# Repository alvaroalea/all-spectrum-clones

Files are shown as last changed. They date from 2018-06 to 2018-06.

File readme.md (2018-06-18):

# Esquema electrico en Kicad de Clones de Sinclair ZX Spectrum

La idea es que a base de borrar trozos de circuito que no interese, generemos nuestro propio clon
personalizado con las siguientes opciones:
 
* ULA - Elegir entre ALTERA o XILING
* MEMORIA RAM- 48 o 128K de RAM
* MEMORIA ROM- 16K o 64K ROM, opciones de ROM mayores con seleccion por dip-switches
* SONIDO - PSG (AY-3-8912 o YM2114), MONO O ABC, OPCION puertos SERIE, AUX
* CINTA - conectores 48K o +3, circuiteria tipo Arlequin o tipo Humble
* VIDEO - RGB o Composite, circuiteria tipo Arlequin
* JOYSTICK - SJS o ATARI, normas SINCLAIR o KEMPSTON
* TECLADO - integrado de 40 Teclas, por transistores (arlequin) o diodos
* TECLADO - conexion facil para teclas externas, DEL, BREAK, CURSORES, BLOQ SHIFT, EXTRA, GRAF
* DISCO - Conexion para interfaz multisistema de wilco (compatible +3), interfaz +D o Interfaz +3
* ALMACENAMIENTO - Interfaz IDE de 8bits, Cartucho IF2, dandanator integrado o con cartuchos VC2.0 

## Futuro:
* DISCO - beta 128, ZXMMC, DIVIDE
* MEMORIA - Usar los 256K tipo ruso
* VIDEO - conector euroconector
* ULA - por chips del arlequin
* IMPRESORA - amstrad / kempston
* RATON - kempston db9, kempston ps2

## Ejemplos:
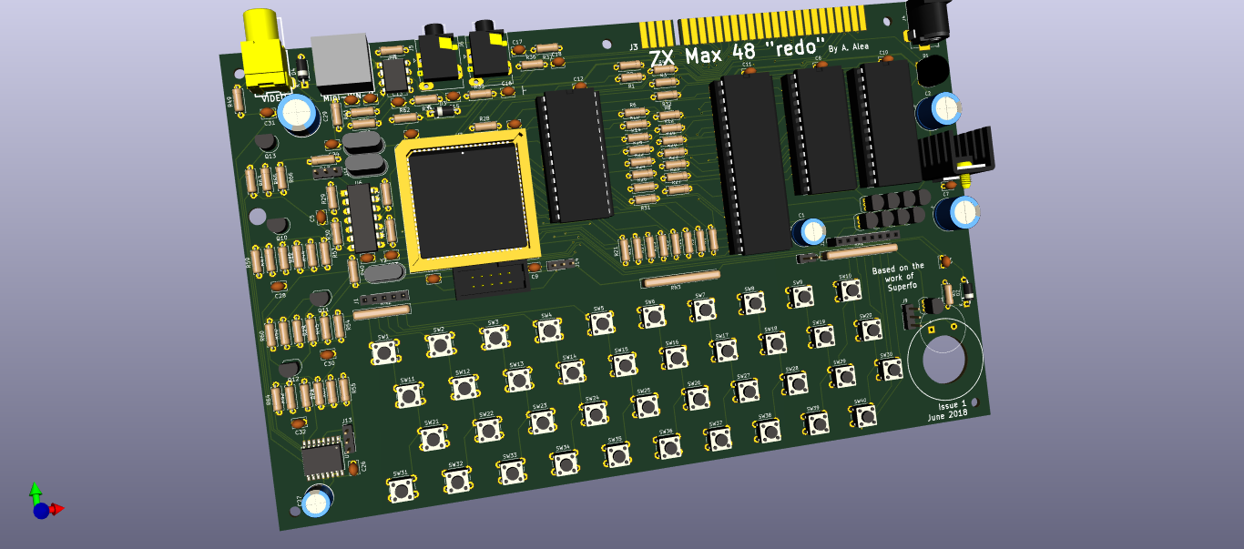
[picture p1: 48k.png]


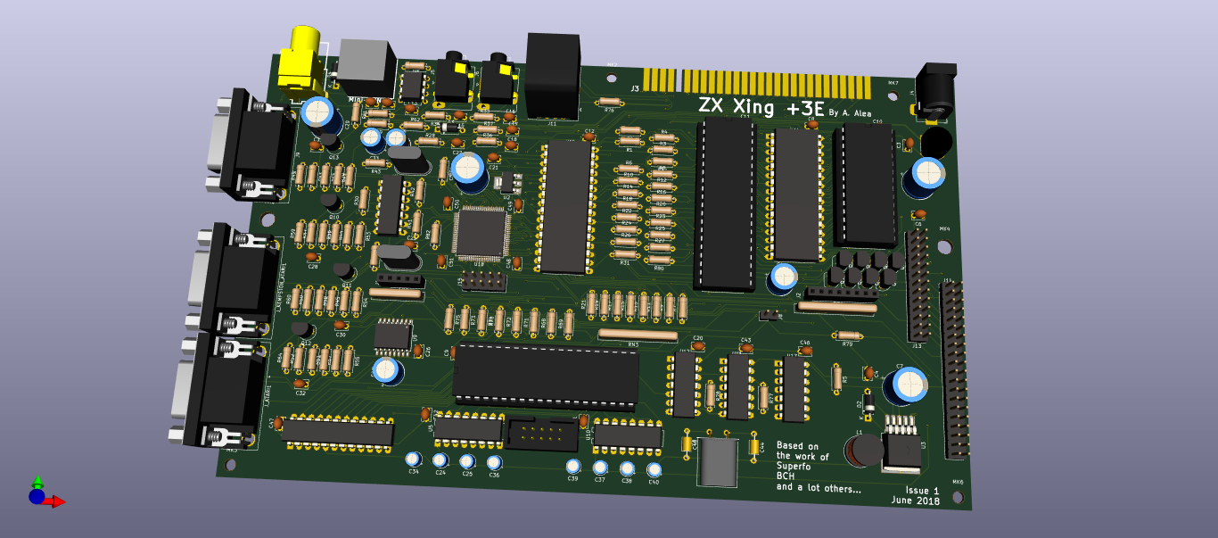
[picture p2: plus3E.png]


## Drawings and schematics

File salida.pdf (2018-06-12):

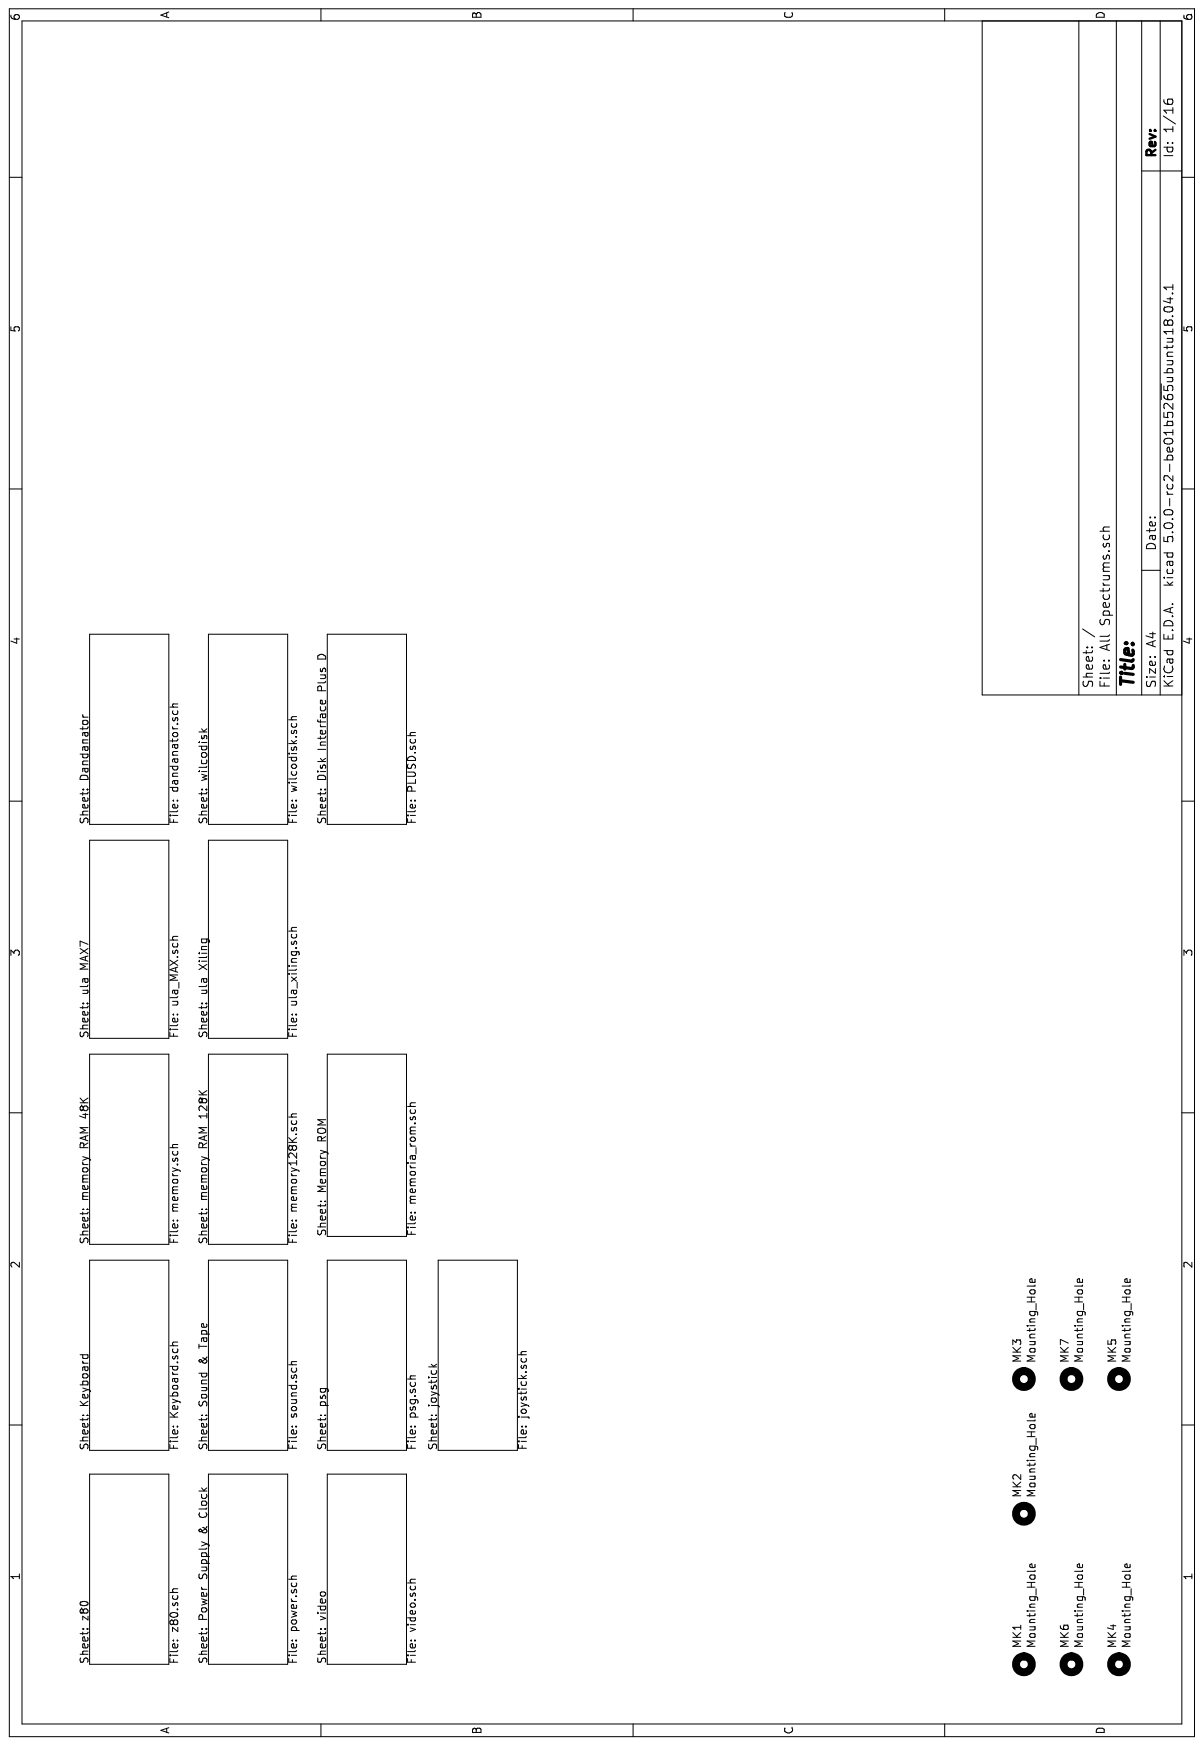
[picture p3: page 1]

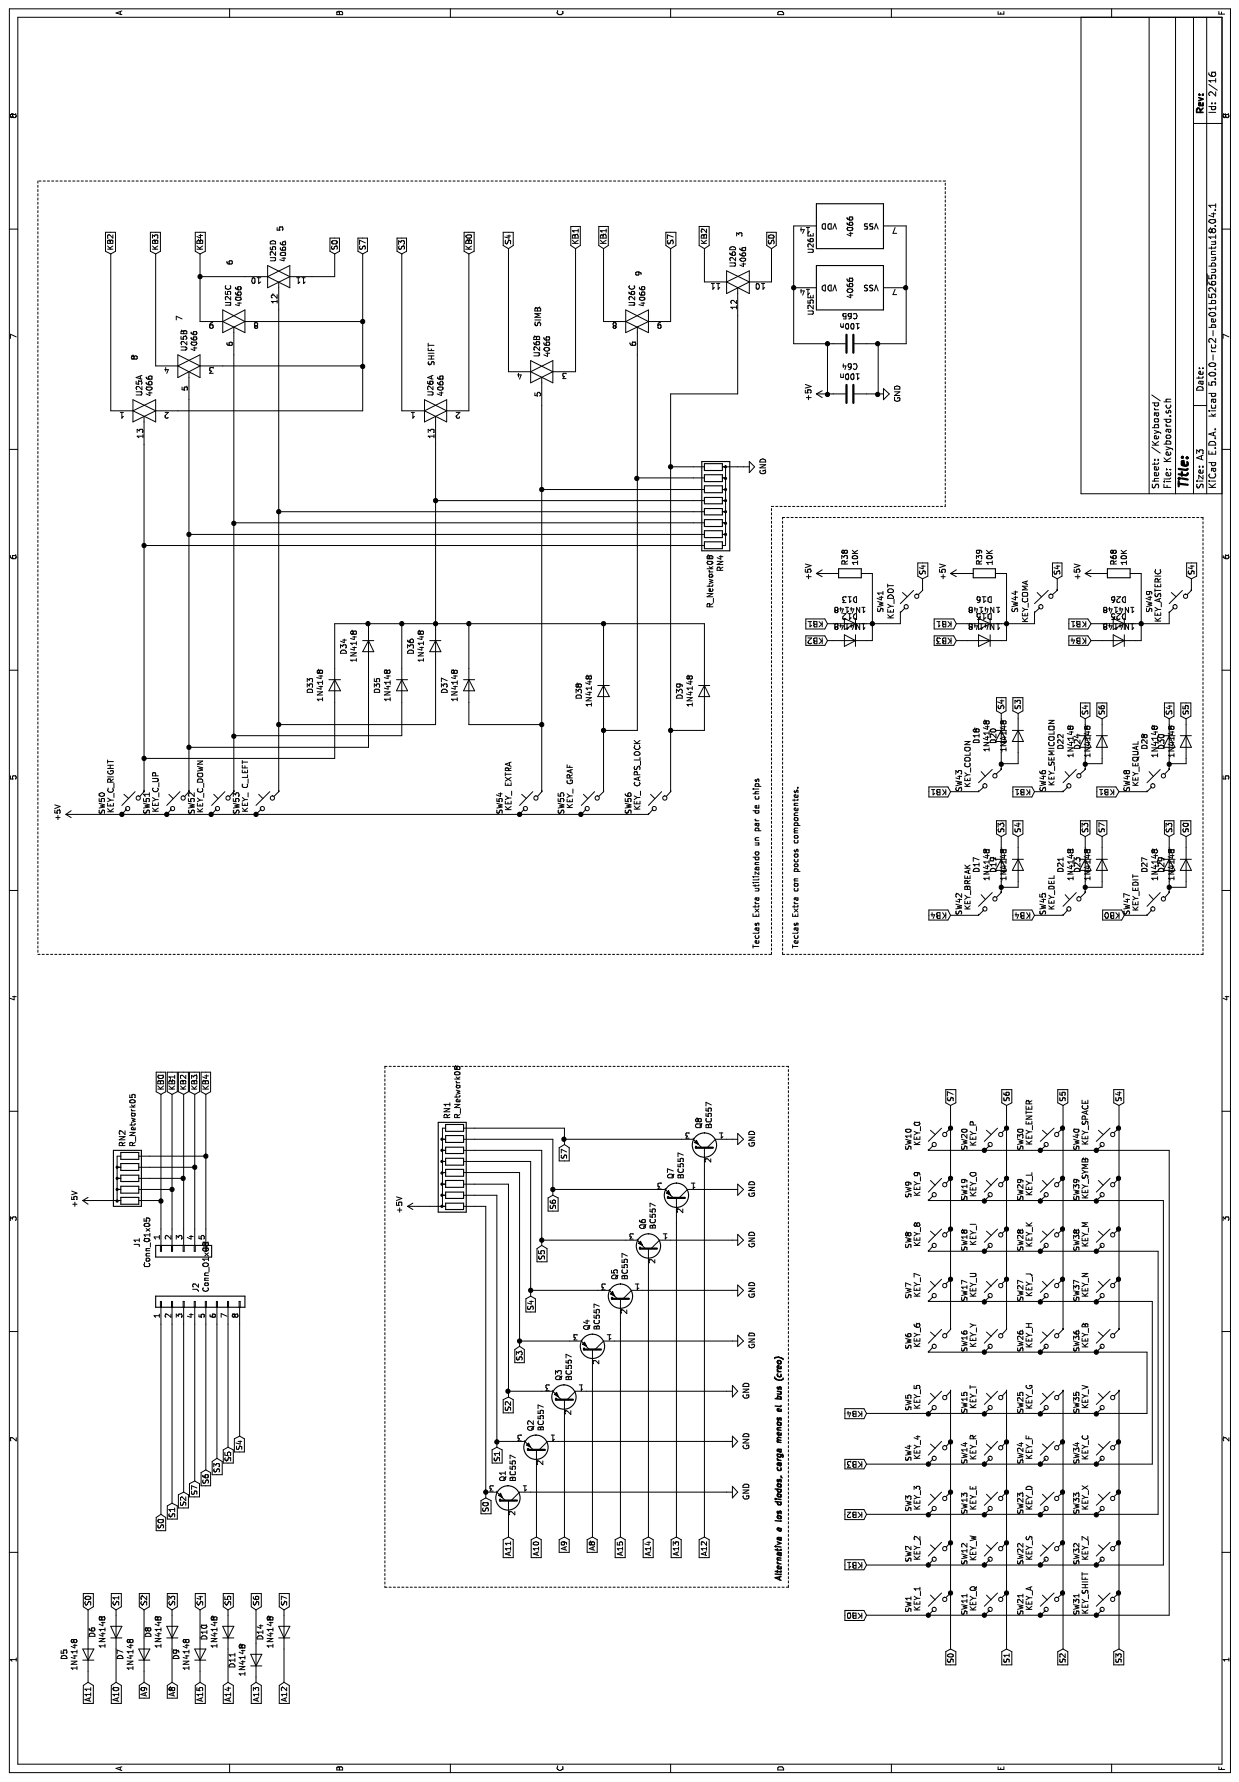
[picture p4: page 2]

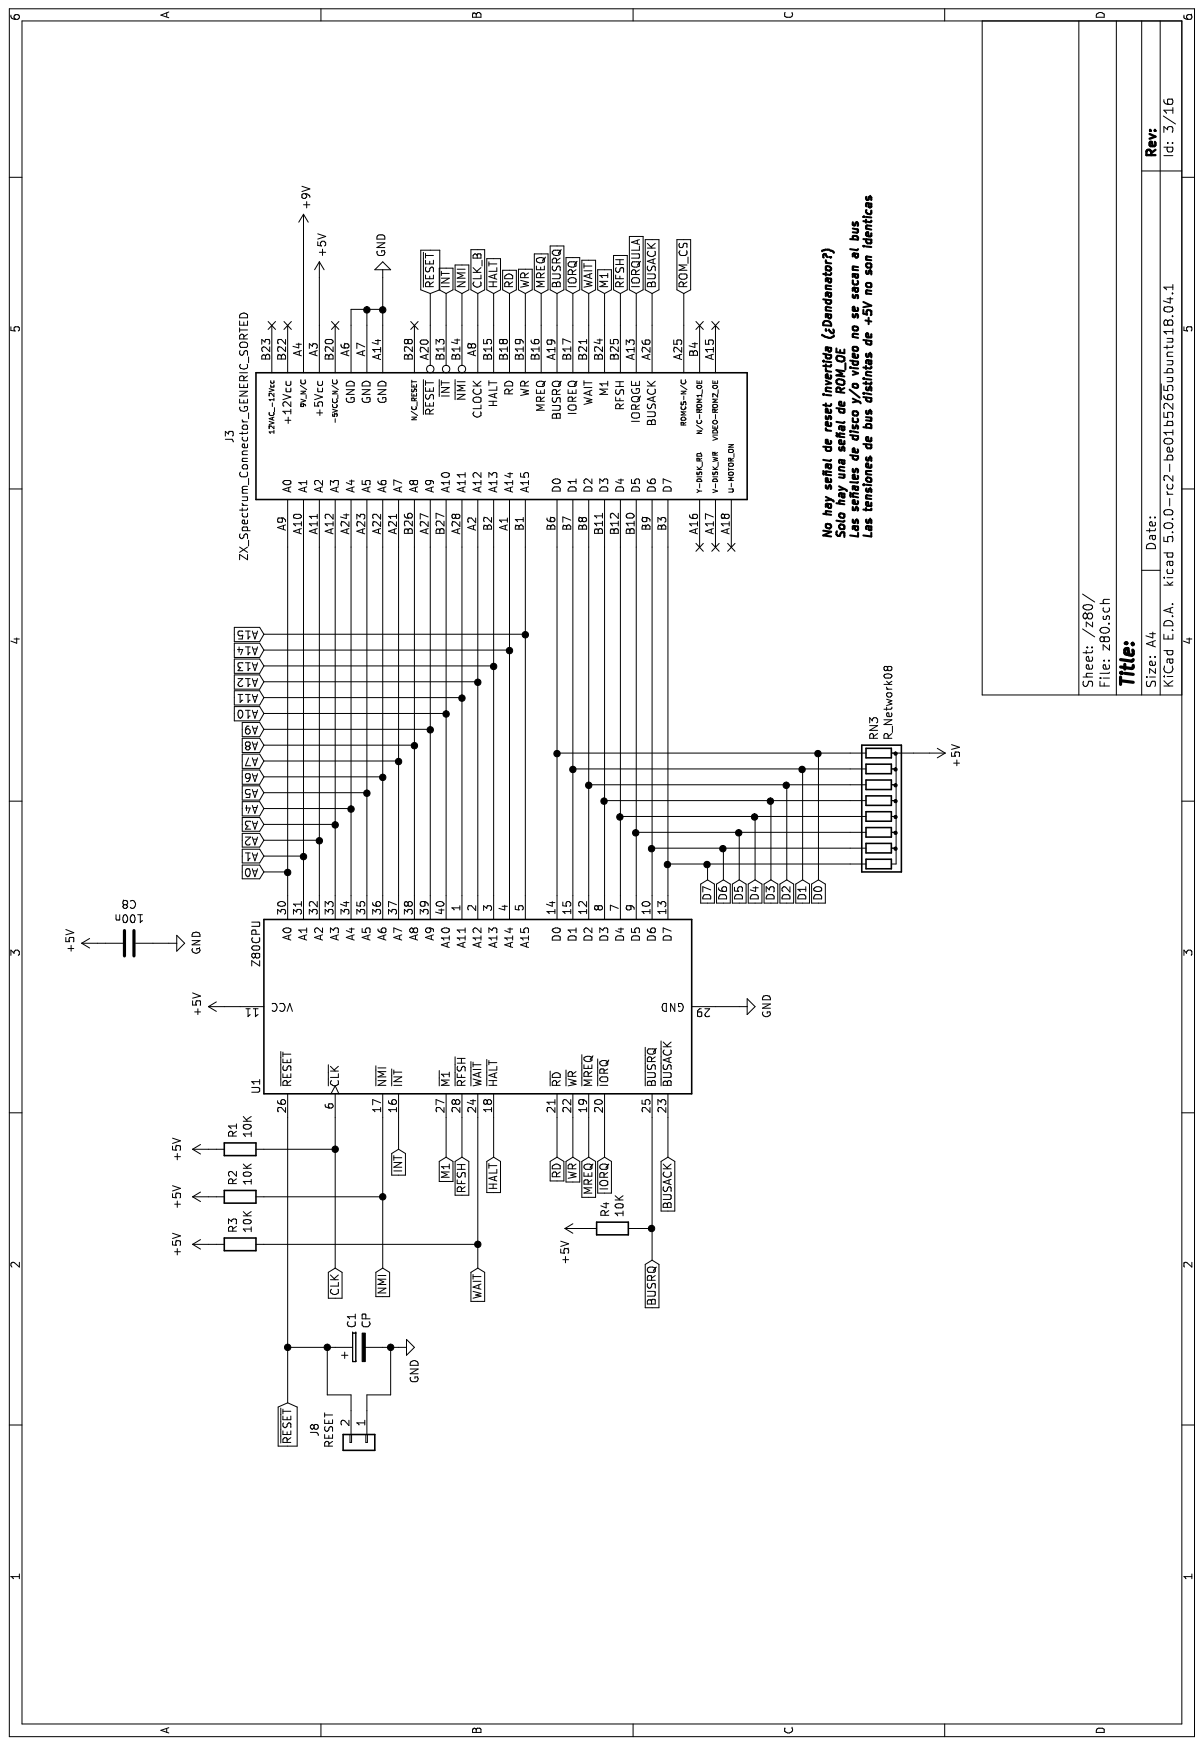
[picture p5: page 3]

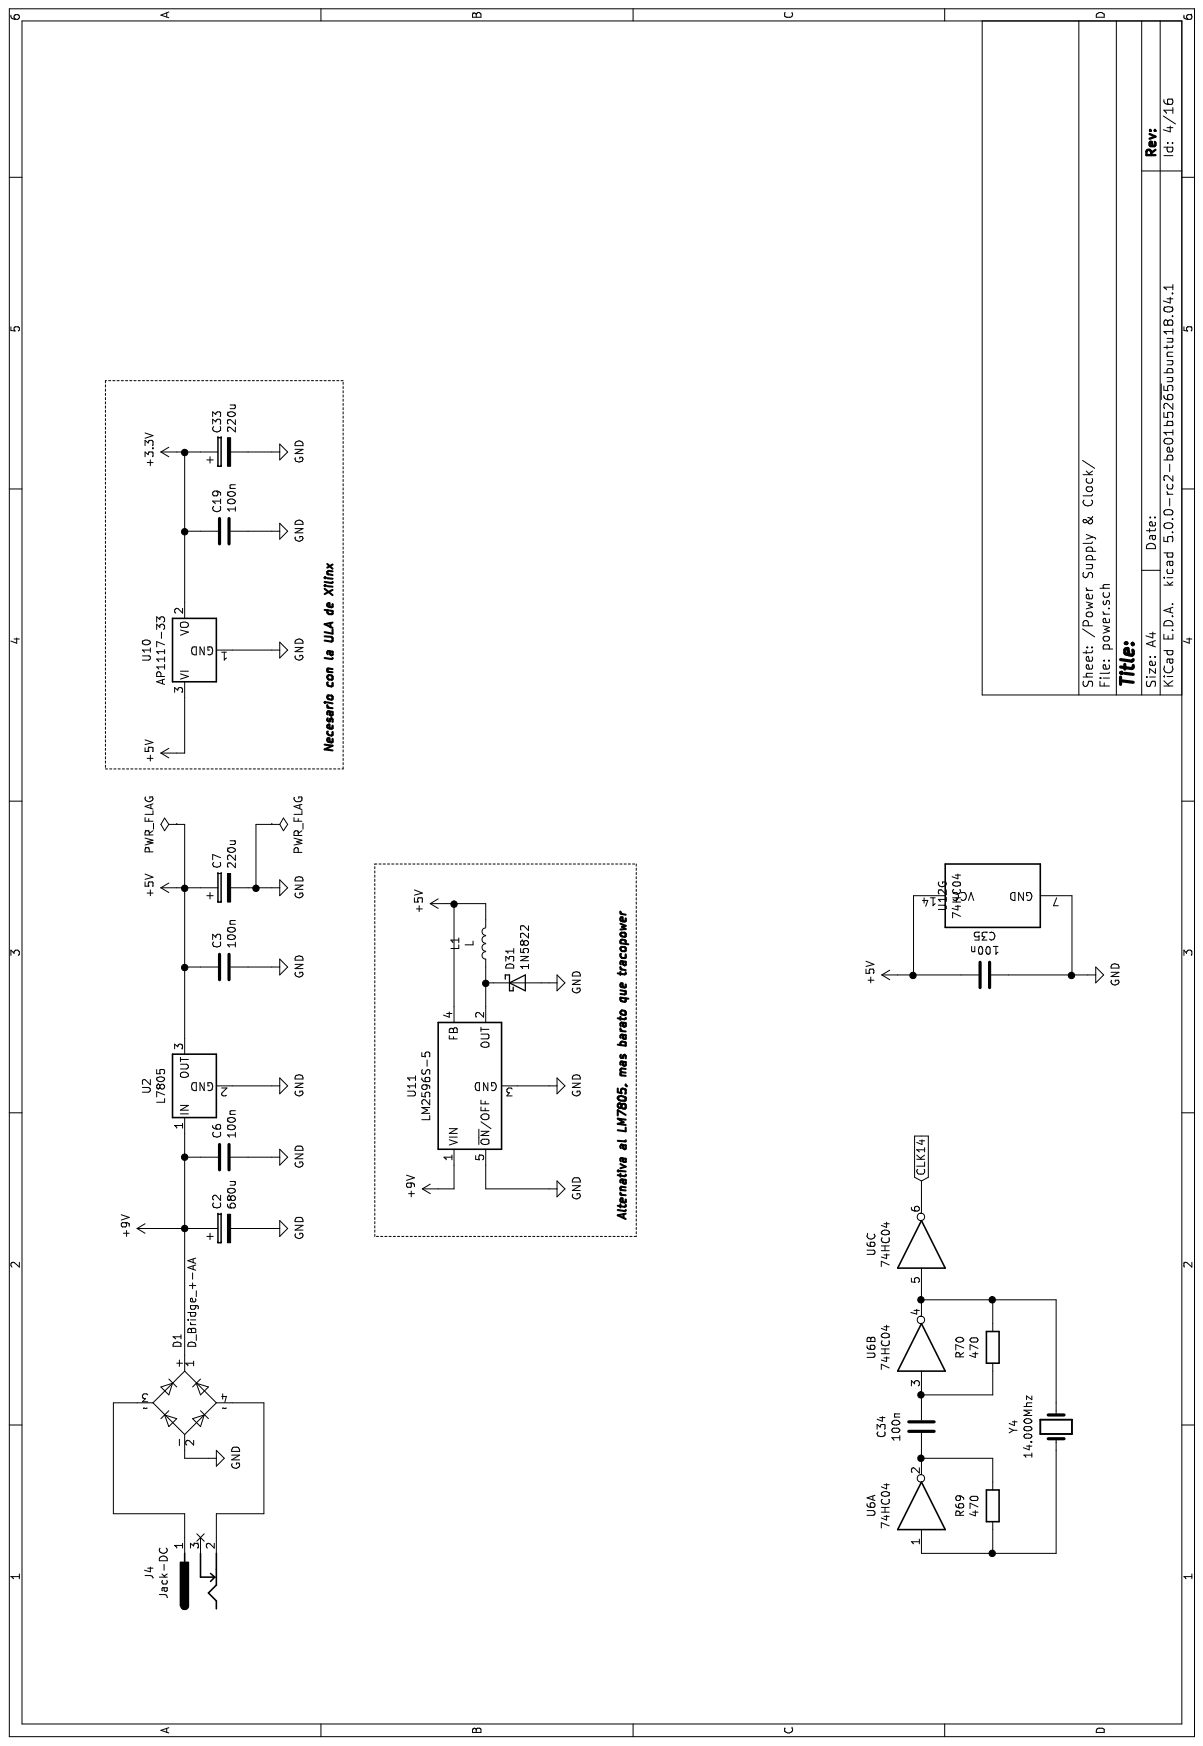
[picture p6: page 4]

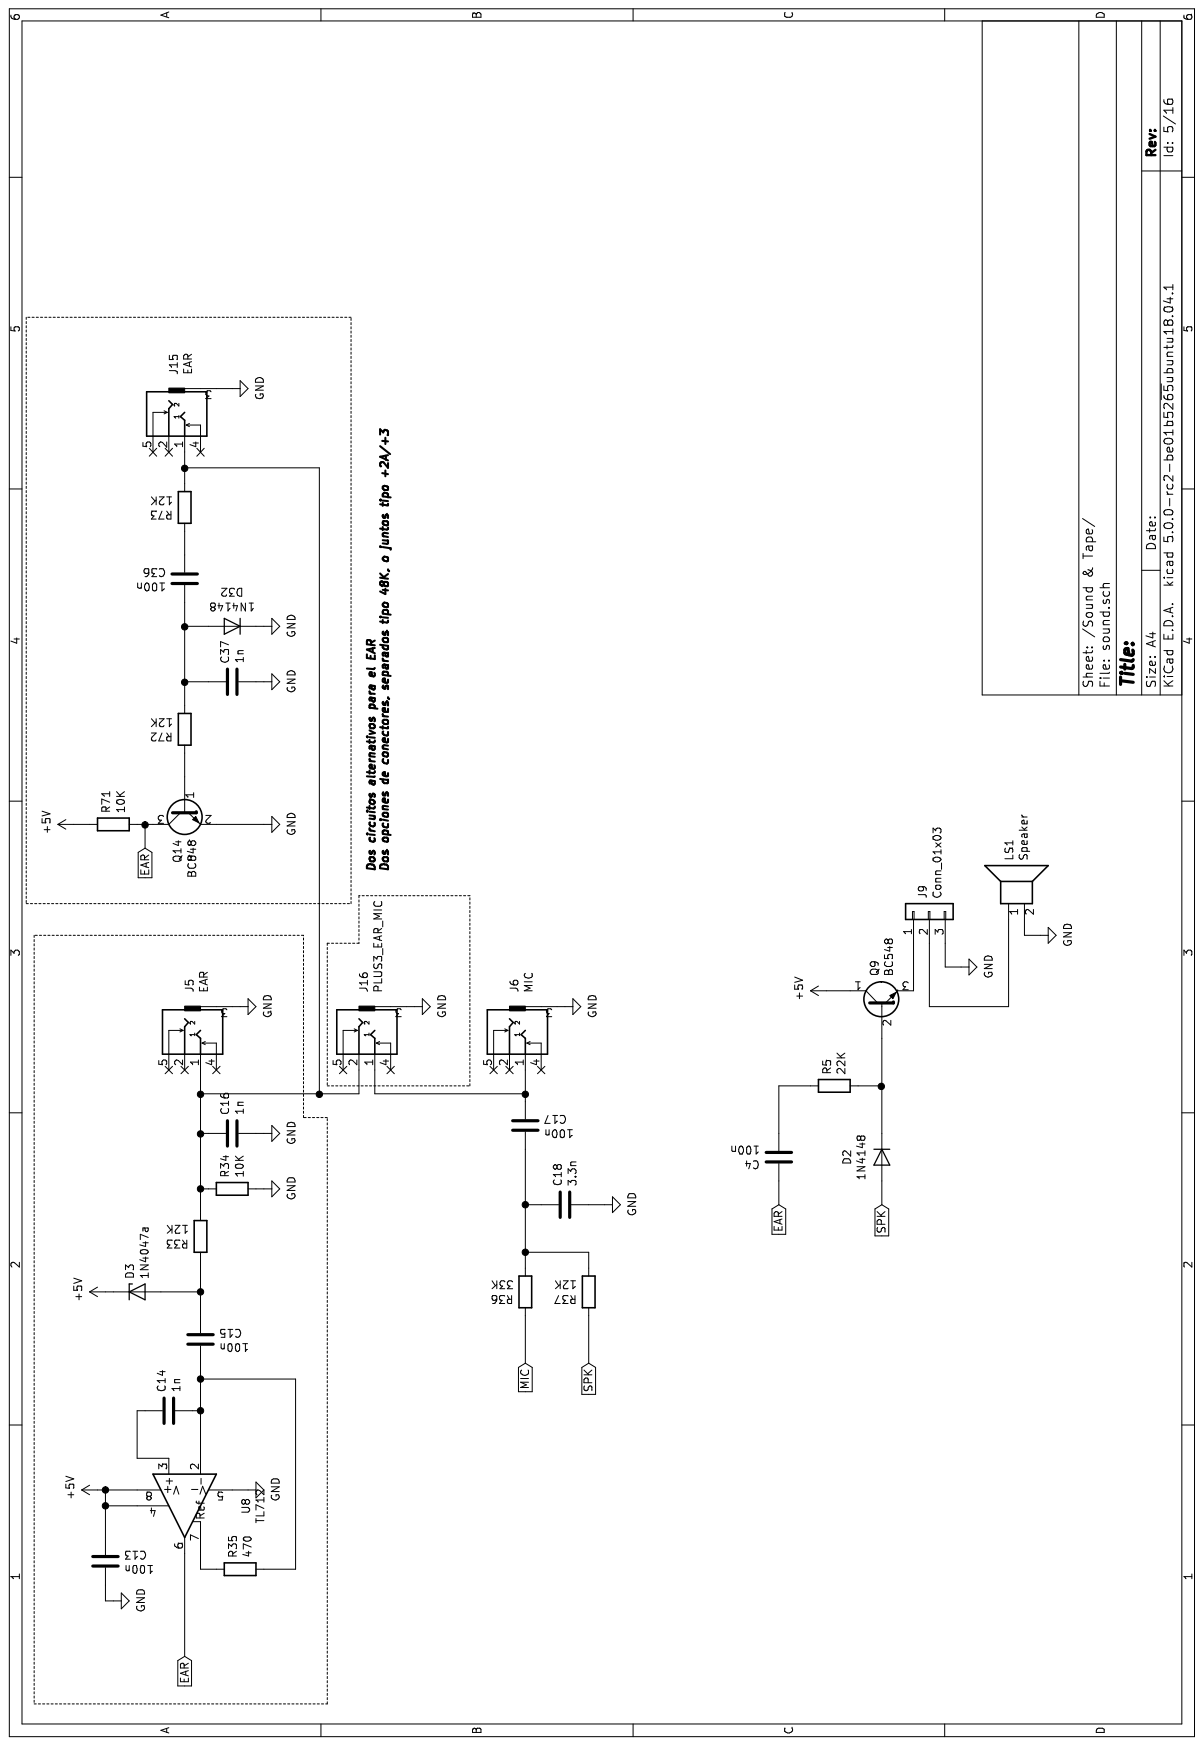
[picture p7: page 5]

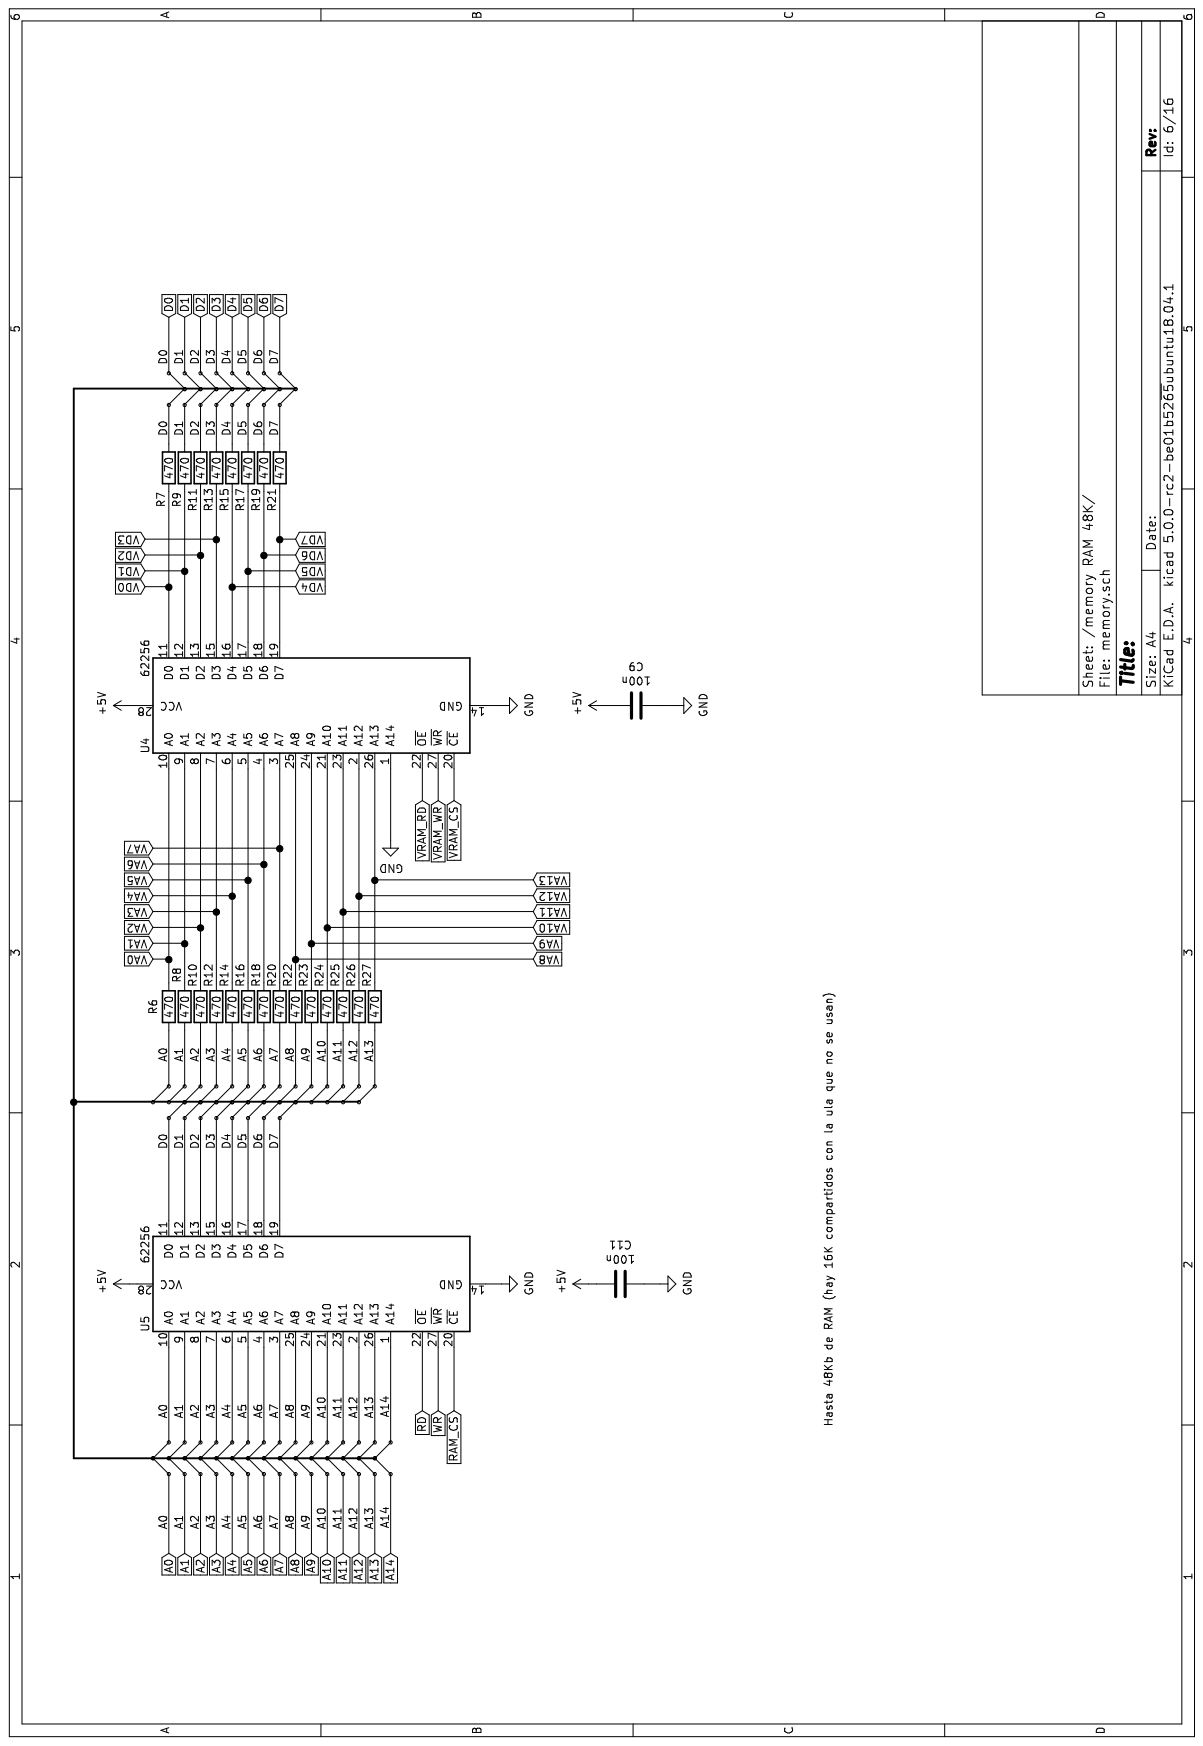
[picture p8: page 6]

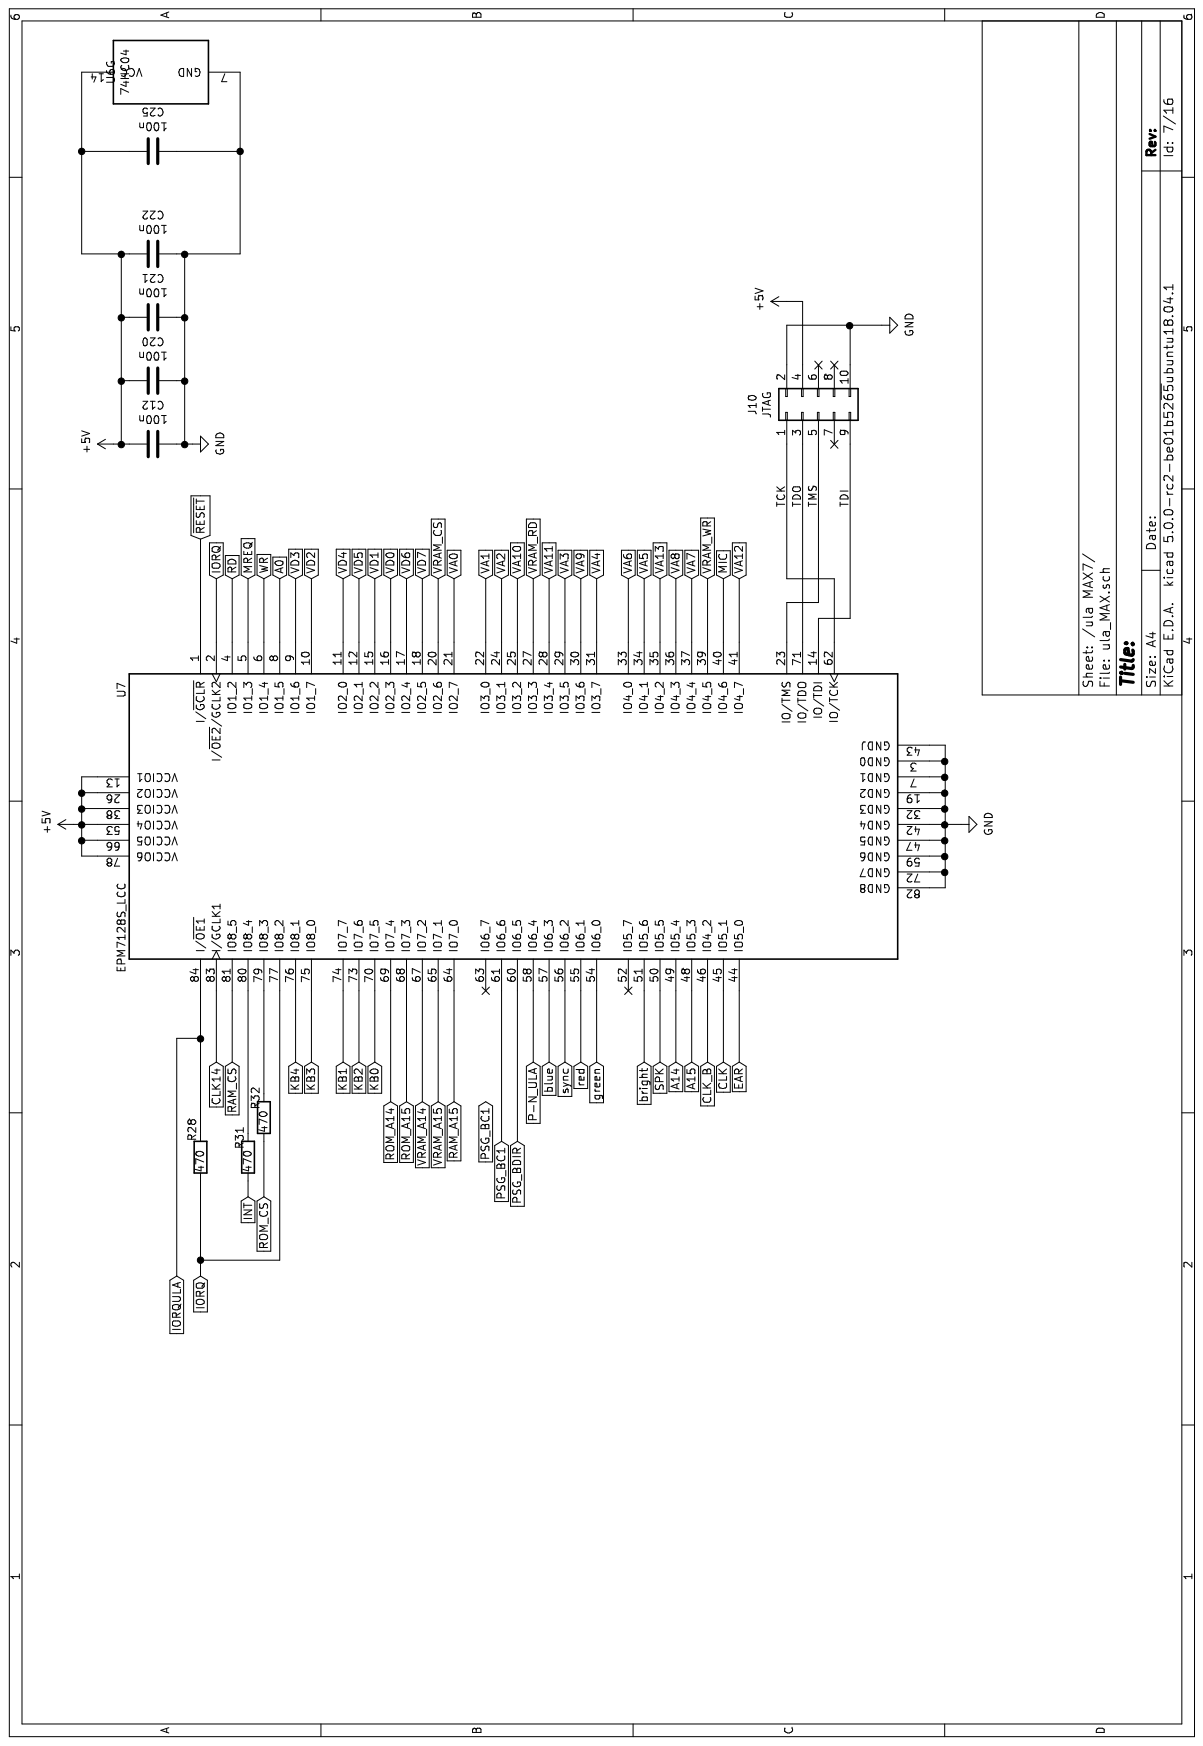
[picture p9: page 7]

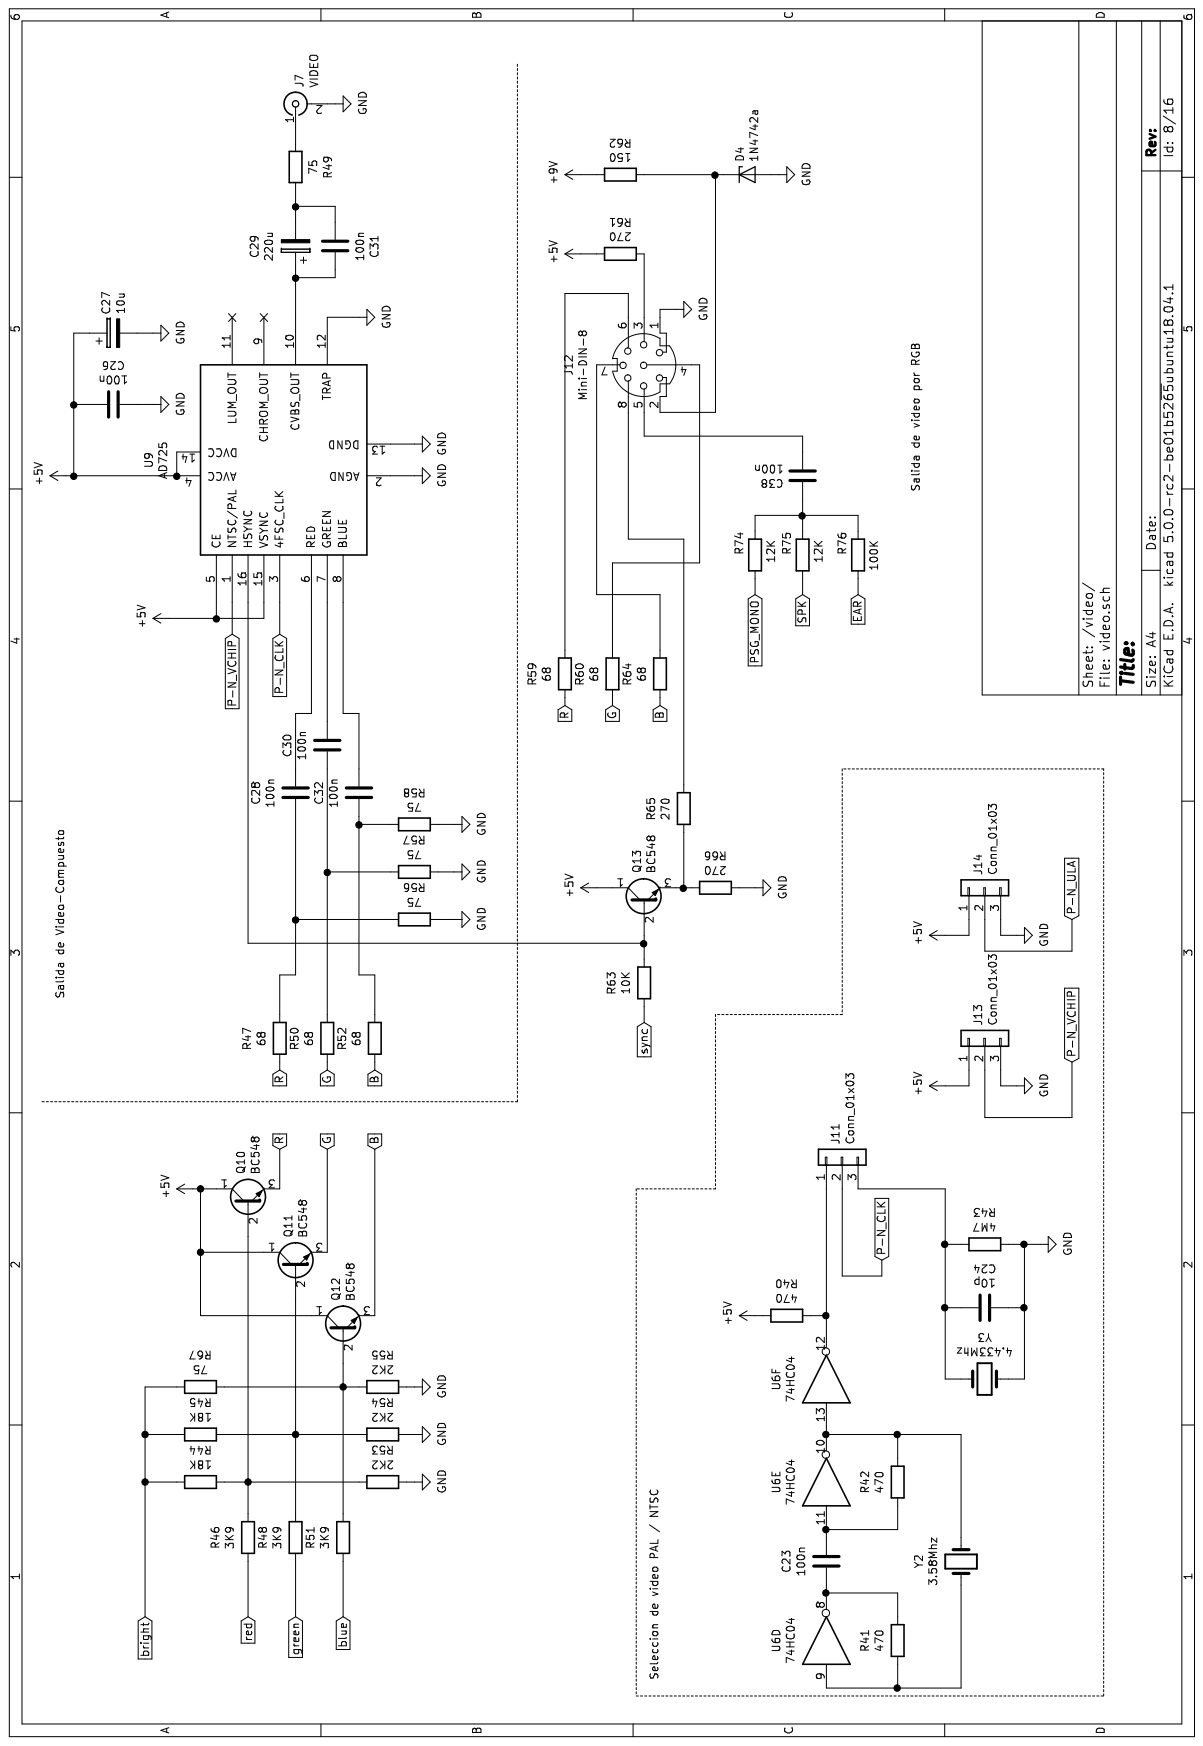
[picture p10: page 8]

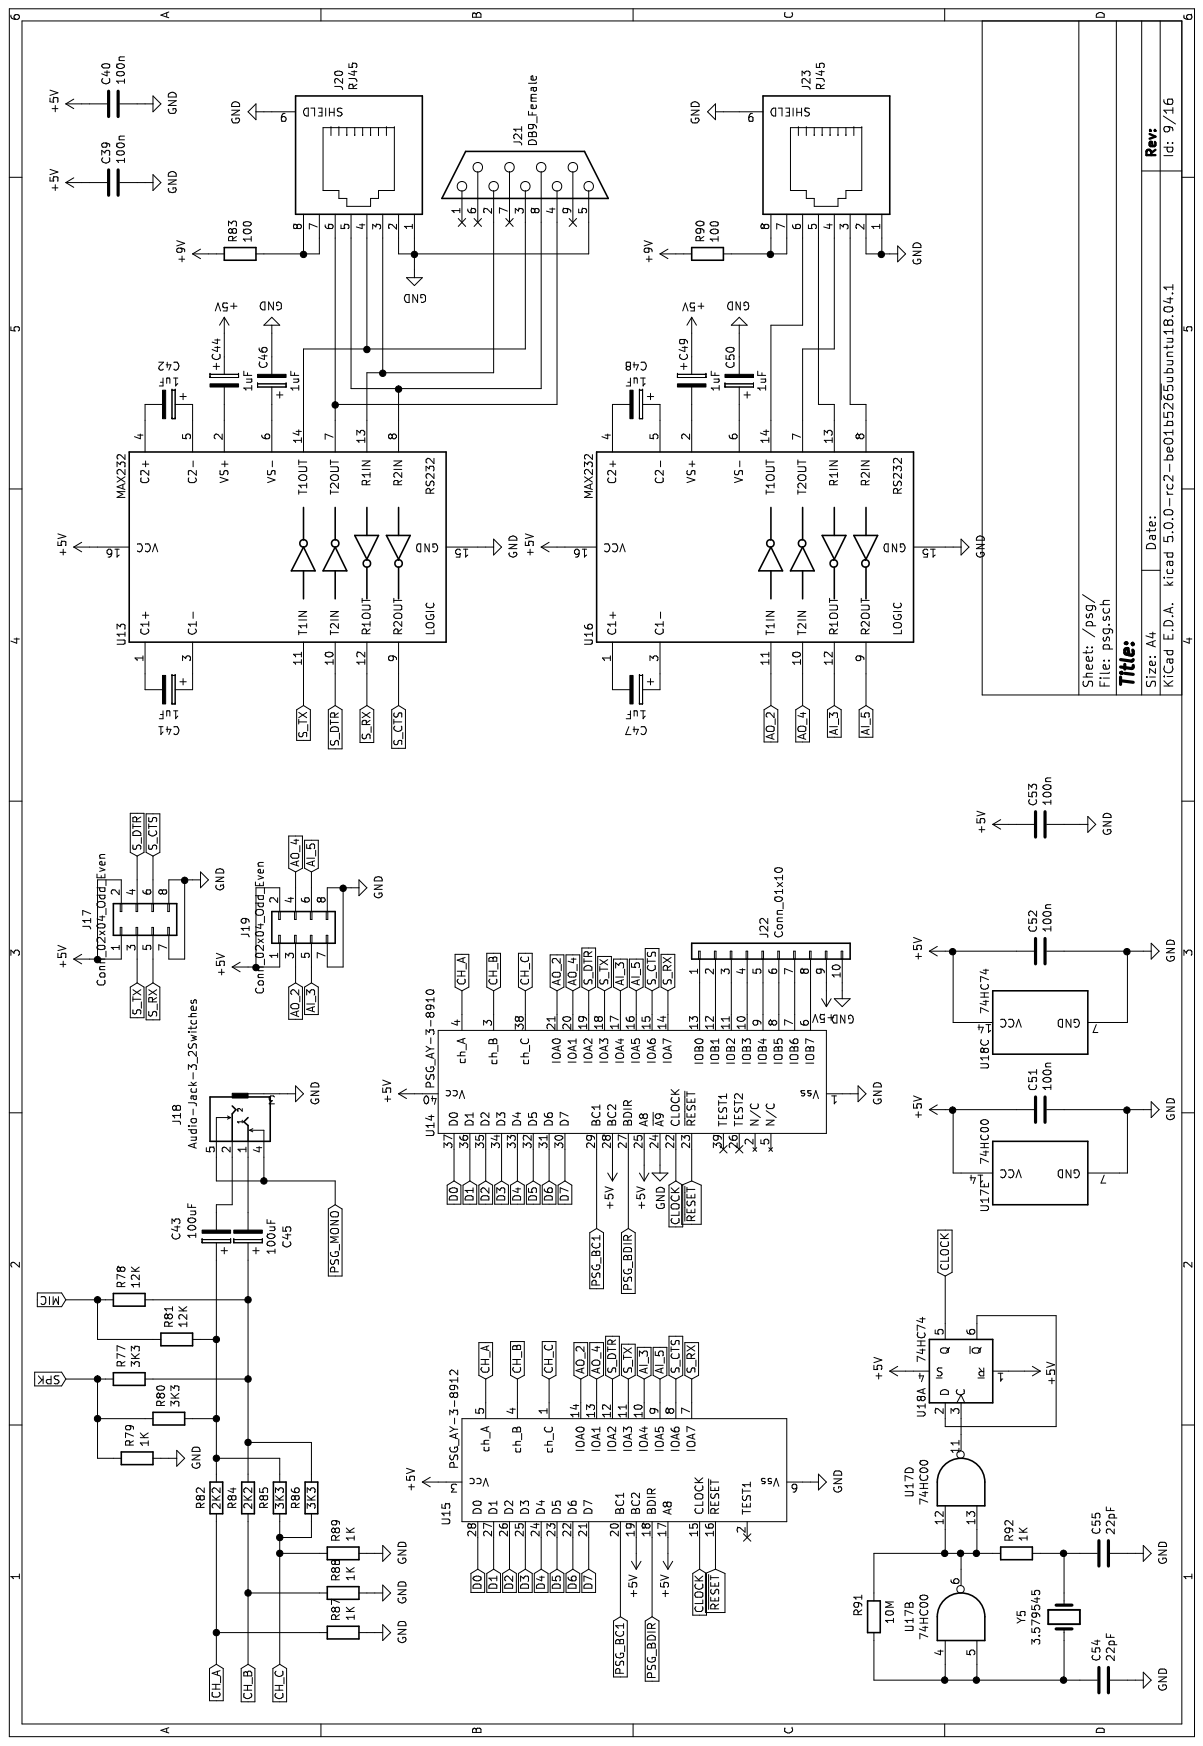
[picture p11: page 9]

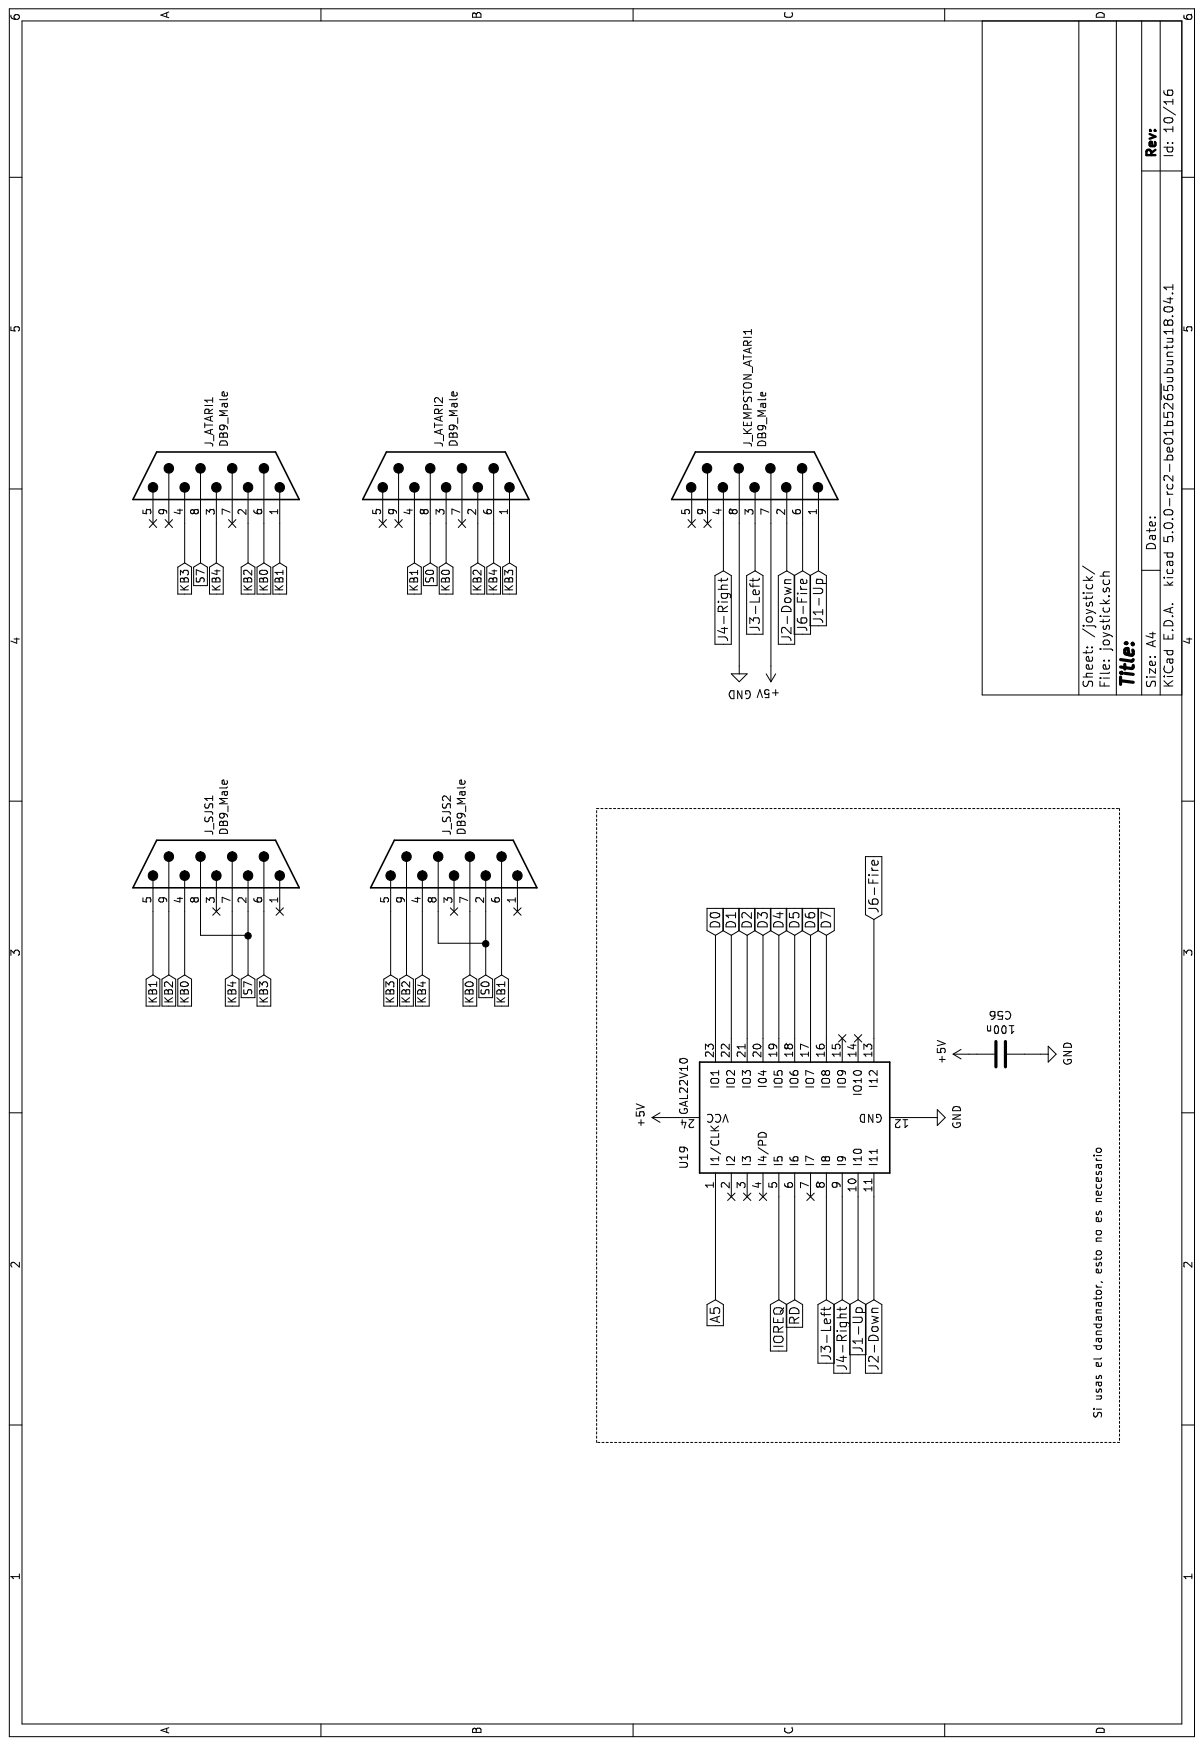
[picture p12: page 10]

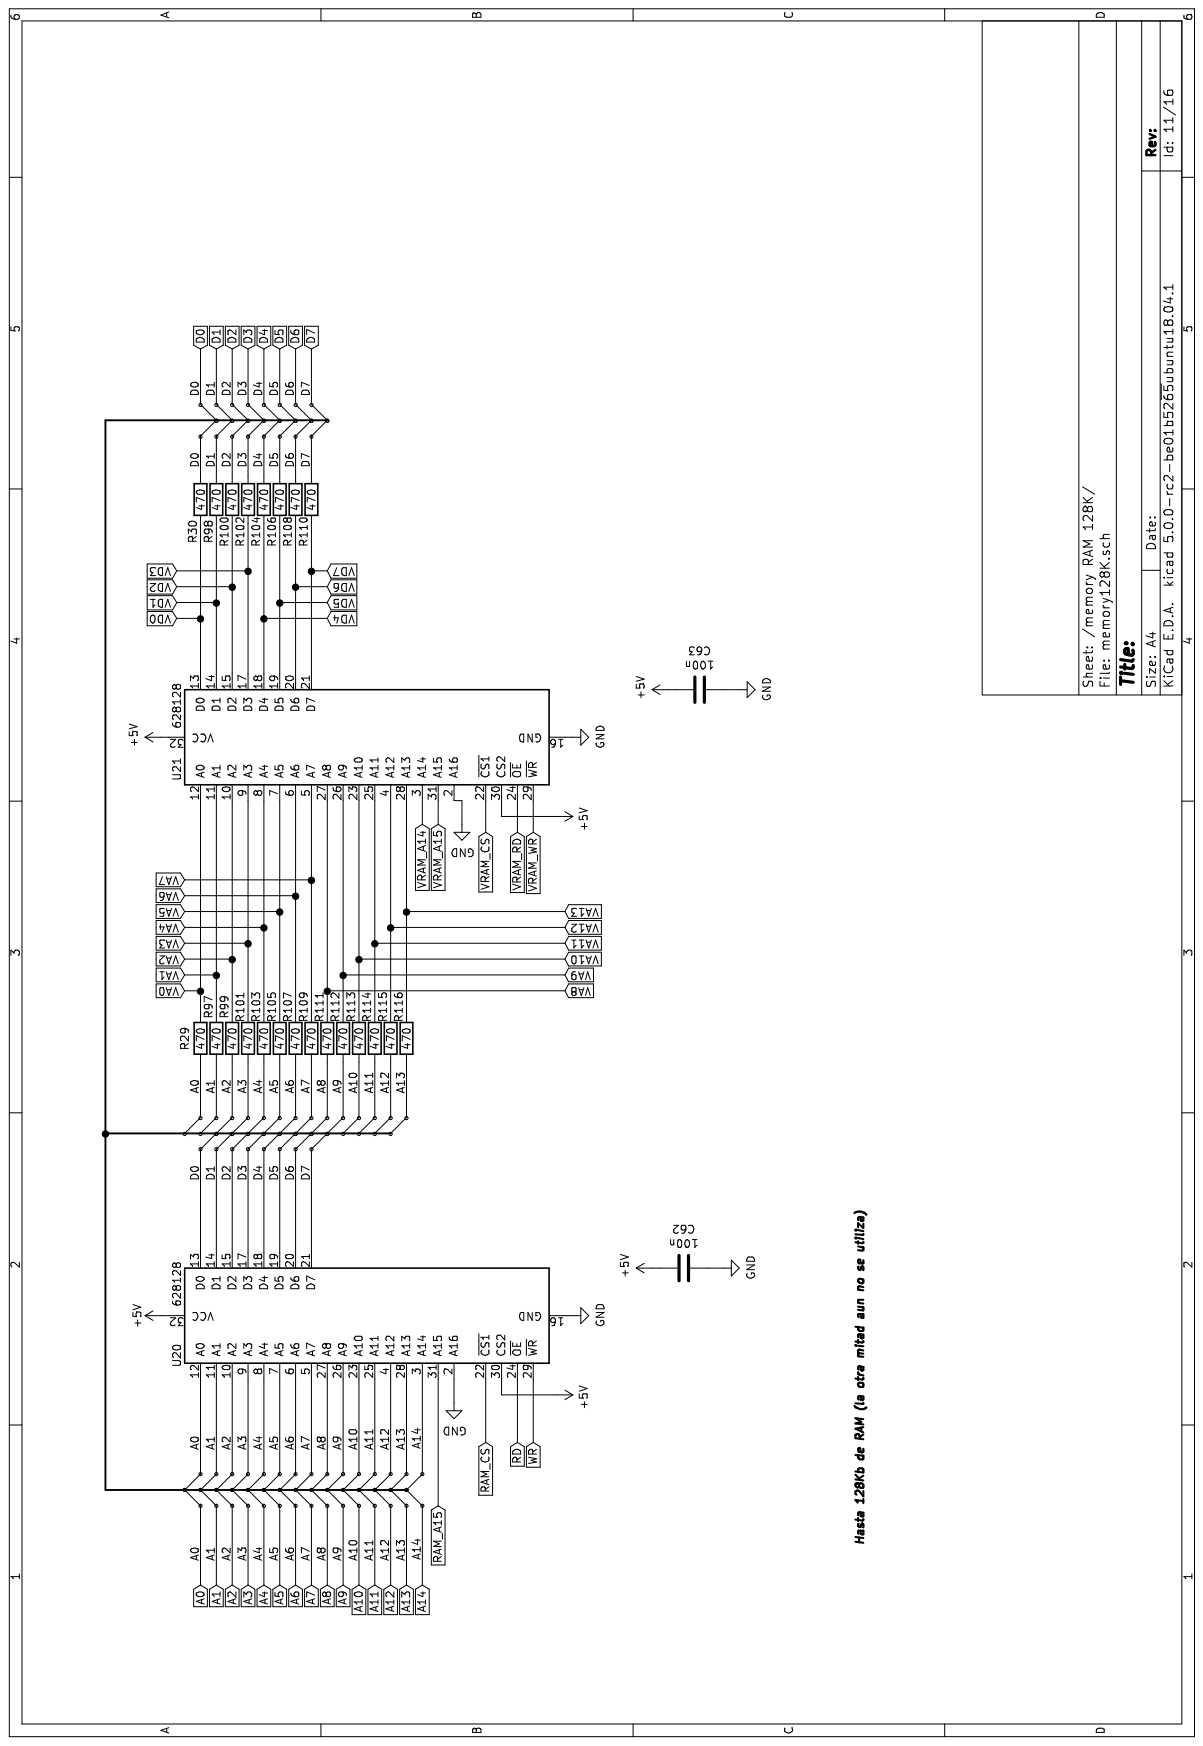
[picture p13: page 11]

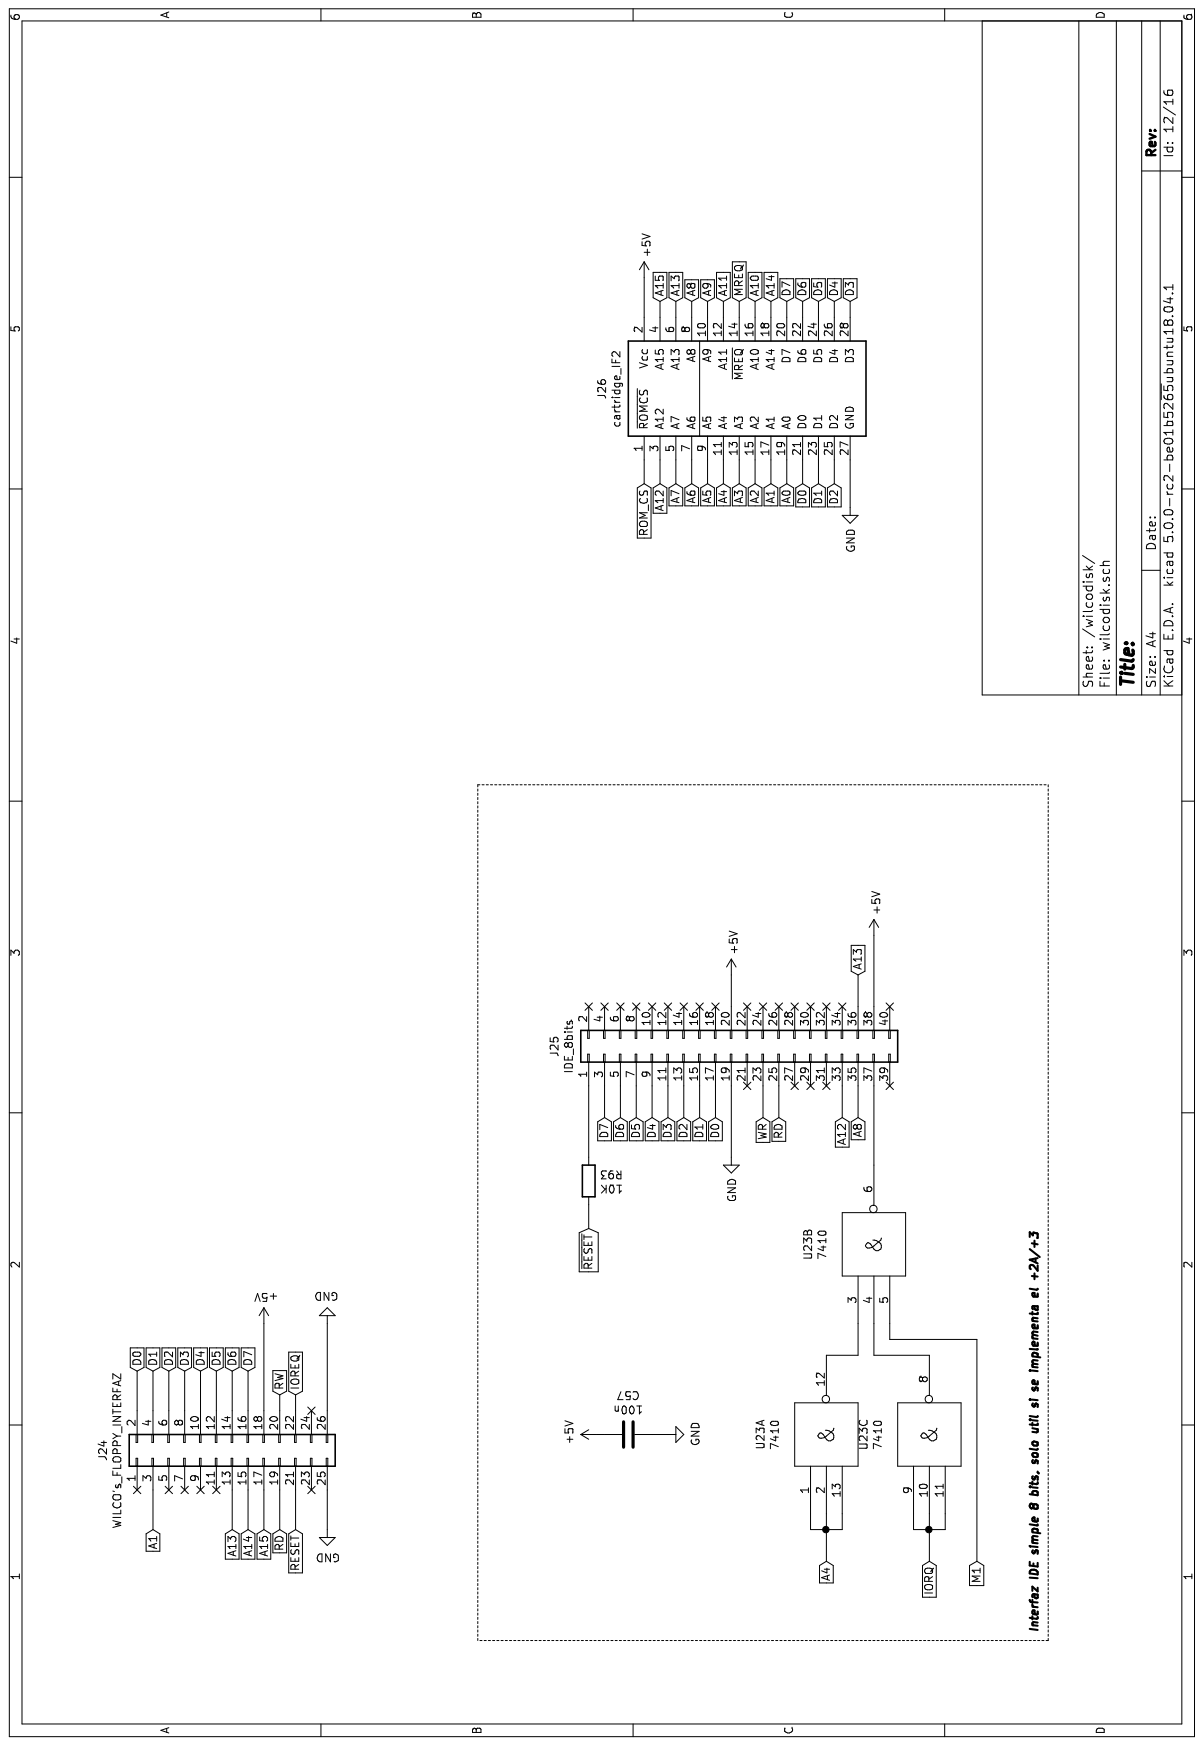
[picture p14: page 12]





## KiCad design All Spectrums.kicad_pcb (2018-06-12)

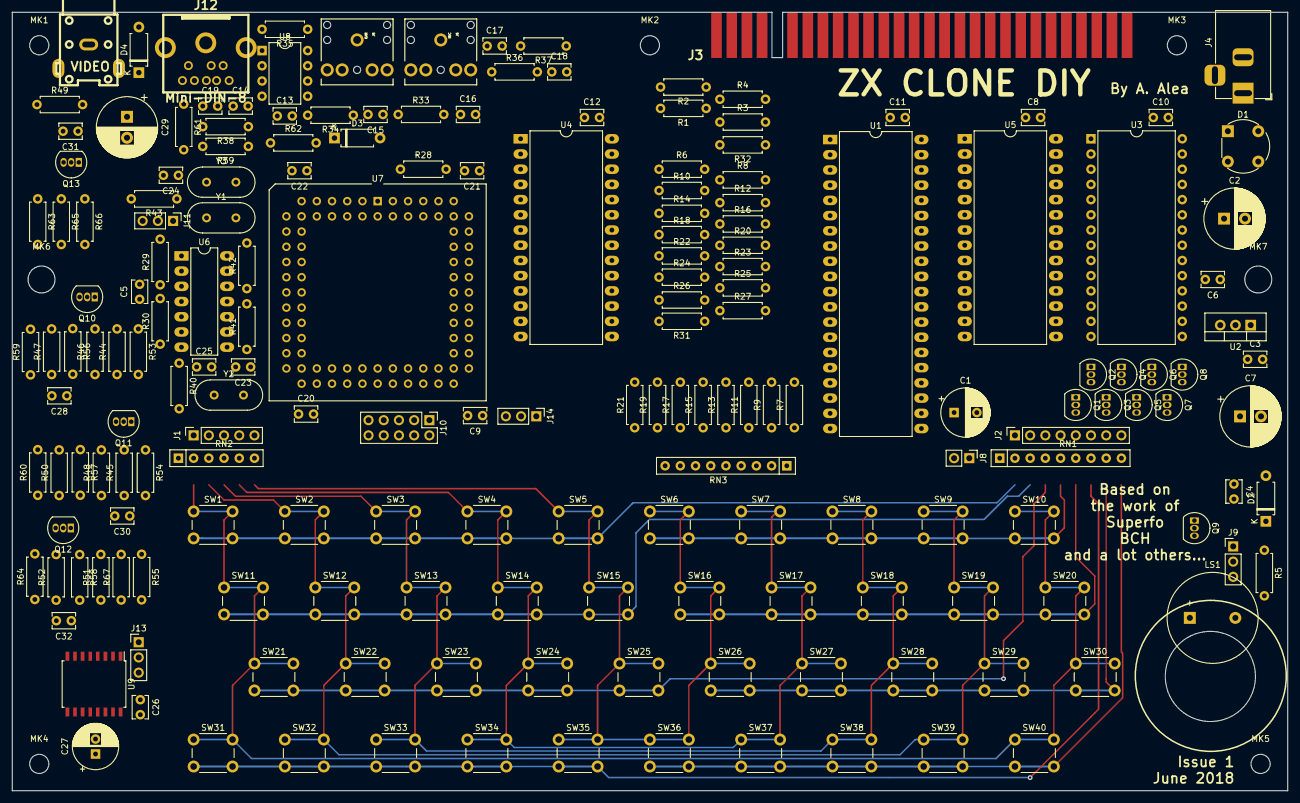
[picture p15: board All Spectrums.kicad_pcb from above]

Board: 2 copper layers, 213.0 x 130.0 mm, 193 parts (0 on the bottom side), 148 nets.

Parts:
C1: CP; CP_Radial_D8.0mm_P3.80mm
C2: 680u; CP_Radial_D10.0mm_P3.50mm
C3, C4, C5, C6, C8, C9, C10, C11, C12, C13, C15, C17, C19, C20, C21, C22, C23, C25, C26, C28, C30, C31, C32: 100n; C_Disc_D3.8mm_W2.6mm_P2.50mm
C7, C29: 220u; CP_Radial_D10.0mm_P3.50mm
C14, C16: 1n; C_Disc_D3.8mm_W2.6mm_P2.50mm
C18: 3.3n; C_Disc_D3.8mm_W2.6mm_P2.50mm
C24: 10p; C_Disc_D3.8mm_W2.6mm_P2.50mm
C27: 10u; CP_Radial_D7.5mm_P2.50mm
D1: D_Bridge_+-AA; Diode_Bridge_Round_D8.9mm
D2: 1N4148; D_A-405_P7.62mm_Horizontal
D3: 1N4047a; D_A-405_P7.62mm_Horizontal
D4: 1N4742a; D_A-405_P7.62mm_Horizontal
J1: Conn_01x05; PinSocket_1x05_P2.54mm_Vertical
J2: Conn_01x08; PinSocket_1x08_P2.54mm_Vertical
J3: ZX_Spectrum_Connector_plus3_SORTED; ZX_EDGE
J4: Jack-DC; BarrelJack_Horizontal
J5: EAR; AUDIO-JACK
J6: MIC; AUDIO-JACK
J7: VIDEO; rca_yellow
J8: RESET; PinHeader_1x02_P2.54mm_Vertical
J9, J11, J13, J14: Conn_01x03; PinHeader_1x03_P2.54mm_Vertical
J10: JTAG; PinHeader_2x05_P2.54mm_Vertical
J12: Mini-DIN-8; minidin-8
LS1: Speaker; Buzzer_15x7.5RM7.6
MK1, MK2, MK3, MK4, MK5: MountingHole_3.2mm_M3
MK6, MK7: MountingHole_4.5mm
Q1, Q2, Q3, Q4, Q5, Q6, Q7, Q8: BC557; TO-92_Inline
Q9, Q10, Q11, Q12, Q13: BC548; TO-92_Inline
R1, R2, R3, R4, R34, R63: 10K; R_Axial_DIN0207_L6.3mm_D2.5mm_P7.62mm_Horizontal
R5: 22K; R_Axial_DIN0207_L6.3mm_D2.5mm_P7.62mm_Horizontal
R6, R7, R8, R9, R10, R11, R12, R13, R14, R15, R16, R17, R18, R19, R20, R21, R22, R23, R24, R25, R26, R27, R28, R29, R30, R31, R32, R35, R40, R41, R42: 470; R_Axial_DIN0207_L6.3mm_D2.5mm_P7.62mm_Horizontal
R33, R37, R39: 12K; R_Axial_DIN0207_L6.3mm_D2.5mm_P7.62mm_Horizontal
R36: 33K; R_Axial_DIN0207_L6.3mm_D2.5mm_P7.62mm_Horizontal
R38: 100K; R_Axial_DIN0207_L6.3mm_D2.5mm_P7.62mm_Horizontal
R43: 4M7; R_Axial_DIN0207_L6.3mm_D2.5mm_P7.62mm_Horizontal
R44, R45: 18K; R_Axial_DIN0207_L6.3mm_D2.5mm_P7.62mm_Horizontal
R46, R48, R51: 3K9; R_Axial_DIN0207_L6.3mm_D2.5mm_P7.62mm_Horizontal
R47, R50, R52, R59, R60, R64: 68; R_Axial_DIN0207_L6.3mm_D2.5mm_P7.62mm_Horizontal
R49, R56, R57, R58, R67: 75; R_Axial_DIN0207_L6.3mm_D2.5mm_P7.62mm_Horizontal
R53, R54, R55: 2K2; R_Axial_DIN0207_L6.3mm_D2.5mm_P7.62mm_Horizontal
R61, R65, R66: 270; R_Axial_DIN0207_L6.3mm_D2.5mm_P7.62mm_Horizontal
R62: 150; R_Axial_DIN0207_L6.3mm_D2.5mm_P7.62mm_Horizontal
RN1, RN3: R_Network08; R_Array_SIP9
RN2: R_Network05; R_Array_SIP6
SW1: KEY_1; SW_PUSH_6mm_H5mm
SW2: KEY_2; SW_PUSH_6mm_H5mm
SW3: KEY_3; SW_PUSH_6mm_H5mm
SW4: KEY_4; SW_PUSH_6mm_H5mm
SW5: KEY_5; SW_PUSH_6mm_H5mm
SW6: KEY_6; SW_PUSH_6mm_H5mm
SW7: KEY_7; SW_PUSH_6mm_H5mm
SW8: KEY_8; SW_PUSH_6mm_H5mm
SW9: KEY_9; SW_PUSH_6mm_H5mm
SW10: KEY_10; SW_PUSH_6mm_H5mm
SW11: KEY_Q; SW_PUSH_6mm_H5mm
SW12: KEY_W; SW_PUSH_6mm_H5mm
SW13: KEY_E; SW_PUSH_6mm_H5mm
SW14: KEY_R; SW_PUSH_6mm_H5mm
SW15: KEY_T; SW_PUSH_6mm_H5mm
SW16: KEY_Y; SW_PUSH_6mm_H5mm
SW17: KEY_U; SW_PUSH_6mm_H5mm
SW18: KEY_I; SW_PUSH_6mm_H5mm
SW19: KEY_O; SW_PUSH_6mm_H5mm
SW20: KEY_P; SW_PUSH_6mm_H5mm
SW21: KEY_A; SW_PUSH_6mm_H5mm
SW22: KEY_S; SW_PUSH_6mm_H5mm
SW23: KEY_D; SW_PUSH_6mm_H5mm
SW24: KEY_F; SW_PUSH_6mm_H5mm
SW25: KEY_G; SW_PUSH_6mm_H5mm
SW26: KEY_H; SW_PUSH_6mm_H5mm
SW27: KEY_J; SW_PUSH_6mm_H5mm
SW28: KEY_K; SW_PUSH_6mm_H5mm
SW29: KEY_L; SW_PUSH_6mm_H5mm
SW30: KEY_ENTER; SW_PUSH_6mm_H5mm
SW31: KEY_SHIFT; SW_PUSH_6mm_H5mm
SW32: KEY_Z; SW_PUSH_6mm_H5mm
SW33: KEY_X; SW_PUSH_6mm_H5mm
SW34: KEY_C; SW_PUSH_6mm_H5mm
SW35: KEY_V; SW_PUSH_6mm_H5mm
SW36: KEY_B; SW_PUSH_6mm_H5mm
SW37: KEY_N; SW_PUSH_6mm_H5mm
SW38: KEY_M; SW_PUSH_6mm_H5mm
SW39: KEY_SYMB; SW_PUSH_6mm_H5mm
SW40: KEY_SPACE; SW_PUSH_6mm_H5mm
U1: Z80CPU; DIP-40_W15.24mm_LongPads
U2: L7805; TO-220-3_Vertical
U3: 27128; DIP-28_W15.24mm
U4, U5: 62256; DIP-28_W15.24mm_LongPads
U6: 74HC04; DIP-14_W7.62mm_LongPads
U7: EPM7128S_LCC; PLCC-84_THT-Socket
U8: TL712; DIP-8_W7.62mm
U9: AD725; SOIC-16W_7.5x10.3mm_P1.27mm
Y1: 14.000Mhz; Crystal_HC18-U_Vertical
Y2: 3.58Mhz; Crystal_HC18-U_Vertical
Y3: 4.433Mhz; Crystal_HC18-U_Vertical

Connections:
+5V: C3.1, C7.1, C8.2, C9.2, C10.2, C11.2, C12.2, C13.1, C20.2, C21.2, C22.2, C25.2, C26.2, C27.1, D3.1, J3.A3, J10.4, J13.1, J14.1, Q9.1, Q10.1, Q11.1, Q12.1, Q13.1, R1.1, R2.1, R3.1, R4.1, R40.2, R61.2, RN1.1, RN2.1, RN3.1, U1.11, U2.3, U3.1, U3.27, U3.28, U4.28, U5.28, U6.14, U7.13, U7.26, U7.38, U7.53, U7.66, U7.78, U8.4, U8.8, U9.4, U9.5, U9.14, U9.15
+9V: C2.1, C6.1, D1.1, J3.A4, R62.2, U2.1
/ula/TCK: J10.1, U7.62
/ula/TDI: J10.9, U7.14
/ula/TDO: J10.3, U7.71
/ula/TMS: J10.5, U7.23
A0: J3.A9, R6.2, U1.30, U3.10, U5.10, U7.8
A1: J3.A10, R8.2, U1.31, U3.9, U5.9
A2: J3.A11, R10.2, U1.32, U3.8, U5.8
A3: J3.A12, R12.2, U1.33, U3.7, U5.7
A4: J3.A24, R14.2, U1.34, U3.6, U5.6
A5: J3.A23, R16.2, U1.35, U3.5, U5.5
A6: J3.A22, R18.2, U1.36, U3.4, U5.4
A7: J3.A21, R20.2, U1.37, U3.3, U5.3
A8: J3.B26, Q6.2, R22.2, U1.38, U3.25, U5.25
A9: J3.A27, Q3.2, R23.2, U1.39, U3.24, U5.24
A10: J3.B27, Q2.2, R24.2, U1.40, U3.21, U5.21
A11: J3.A28, Q1.2, R25.2, U1.1, U3.23, U5.23
A12: J3.A2, Q4.2, R26.2, U1.2, U3.2, U5.2
A13: J3.B2, Q5.2, R27.2, U1.3, U3.26, U5.26
A14: J3.A1, Q7.2, U1.4, U5.1, U7.49
A15: J3.B1, Q8.2, U1.5, U7.48
AUDIO_OUT: C19.2, J12.5
B: Q12.3, R52.2, R64.2
BUSACK: J3.A26, U1.23
BUSRQ: J3.A19, R4.2, U1.25
CLK: R1.2, U1.6, U7.45
CLK14: U6.6, U7.83
CLK_B: J3.A8, U7.46
D0: J3.B6, R7.1, RN3.2, U1.14, U3.11, U5.11
D1: J3.B7, R9.1, RN3.3, U1.15, U3.12, U5.12
D2: J3.B8, R11.1, RN3.4, U1.12, U3.13, U5.13
D3: J3.B11, R13.1, RN3.5, U1.8, U3.15, U5.15
D4: J3.B12, R15.1, RN3.6, U1.7, U3.16, U5.16
D5: J3.B10, R17.1, RN3.7, U1.9, U3.17, U5.17
D6: J3.B9, R19.1, RN3.8, U1.10, U3.18, U5.18
D7: J3.B3, R21.1, RN3.9, U1.13, U3.19, U5.19
EAR: C4.1, R38.1, U7.44, U8.6
G: Q11.3, R50.2, R60.2
GND: C1.2, C2.2, C3.2, C6.2, C7.2, C8.1, C9.1, C10.1, C11.1, C12.1, C13.2, C16.2, C18.2, C20.1, C21.1, C22.1, C24.1, C25.1, C26.1, C27.2, D1.2, D4.2, J3.A6, J3.A7, J3.A14, J7.2, J8.1, J9.3, J10.2, J10.10, J12.1, J13.3, J14.3, LS1.2, Q1.1, Q2.1, Q3.1, Q4.1, Q5.1, Q6.1, Q7.1, Q8.1, R34.2, R43.1, R53.1, R54.1, R55.1, R56.1, R57.1, R58.1, R66.1, U1.29, U2.2, U3.14, U4.1, U4.14, U5.14, U6.7, U7.3, U7.7, U7.19, U7.32, U7.42, U7.43, U7.47, U7.59, U7.72, U7.82, U8.5, U9.2, U9.12, U9.13, Y3.2
HALT: J3.B15, U1.18
INT: J3.B13, R31.1, U1.16
IORQ: J3.B17, R28.1, U1.20, U7.2, U7.77
IORQULA: J3.A13, R28.2, U7.84
KB0: J1.1, RN2.2, SW1.1, SW10.1, SW11.1, SW20.1, SW21.1, SW30.1, SW31.1, SW40.1, U7.70
KB1: J1.2, RN2.3, SW2.1, SW9.1, SW12.1, SW19.1, SW22.1, SW29.1, SW32.1, SW39.1, U7.74
KB2: J1.3, RN2.4, SW3.1, SW8.1, SW13.1, SW18.1, SW23.1, SW28.1, SW33.1, SW38.1, U7.73
KB3: J1.4, RN2.5, SW4.1, SW7.1, SW14.1, SW17.1, SW24.1, SW27.1, SW34.1, SW37.1, U7.75
KB4: J1.5, RN2.6, SW5.1, SW6.1, SW15.1, SW16.1, SW25.1, SW26.1, SW35.1, SW36.1, U7.76
M1: J3.B24, U1.27
MIC: R36.1, U7.40
MREQ: J3.B16, U1.19, U7.5
NMI: J3.B14, R2.2, U1.17
unnamed: C4.2, R5.1
unnamed: C5.1, R30.2, U6.3
unnamed: C5.2, R29.1, U6.2
unnamed: C14.1, U8.3
unnamed: C14.2, C15.2, R35.2, U8.2
unnamed: C15.1, D3.2, R33.1
unnamed: C16.1, R33.2, R34.1
unnamed: C17.2, C18.1, R36.2, R37.2
unnamed: C19.1, R38.2, R39.2
unnamed: C23.1, R42.2, U6.11
unnamed: C23.2, R41.1, U6.8
unnamed: C24.2, J11.3, R43.2, Y3.1
unnamed: C28.1, U9.6
unnamed: C28.2, R47.1, R56.2
unnamed: C29.1, C31.1, U9.10
unnamed: C29.2, C31.2, R49.1
unnamed: C30.1, U9.7
unnamed: C30.2, R50.1, R57.2
unnamed: C32.1, U9.8
unnamed: C32.2, R52.1, R58.2
unnamed: D1.3, J4.1
unnamed: D1.4, J4.2
unnamed: D2.1, Q9.2, R5.2
unnamed: D4.1, J12.2, R62.1
unnamed: J7.1, R49.2
unnamed: J9.1, Q9.3
unnamed: J9.2, LS1.1
unnamed: J11.1, R40.1, U6.12
unnamed: J12.3, R61.1
unnamed: J12.4, R60.1
unnamed: J12.6, R59.1
unnamed: J12.7, R64.1
unnamed: J12.8, R65.1
unnamed: Q10.2, R44.1, R46.1, R53.2
unnamed: Q11.2, R45.1, R48.1, R54.2
unnamed: Q12.2, R51.1, R55.2, R67.1
unnamed: Q13.2, R63.1, U9.16
unnamed: Q13.3, R65.2, R66.2
unnamed: R29.2, U6.1, Y1.1
unnamed: R30.1, U6.4, U6.5, Y1.2
unnamed: R31.2, U7.80
unnamed: R32.2, U7.79
unnamed: R35.1, U8.7
unnamed: R41.2, U6.9, Y2.1
unnamed: R42.1, U6.10, U6.13, Y2.2
P-N_CLK: J11.2, U9.3
P-N_ULA: J14.2, U7.58
P-N_VCHIP: J13.2, U9.1
R: Q10.3, R47.2, R59.2
RAM_CS: U5.20, U7.81
RD: J3.B18, U1.21, U3.22, U5.22, U7.4
RFSH: J3.B25, U1.28
ROM_CS: J3.A25, R32.1, U3.20
S0: J2.1, Q1.3, RN1.2, SW1.2, SW2.2, SW3.2, SW4.2, SW5.2
S1: J2.2, Q2.3, RN1.3, SW11.2, SW12.2, SW13.2, SW14.2, SW15.2
S2: J2.3, Q3.3, RN1.4, SW21.2, SW22.2, SW23.2, SW24.2, SW25.2
S3: J2.4, Q4.3, RN1.5, SW6.2, SW7.2, SW8.2, SW9.2, SW10.2
S4: J2.5, Q5.3, RN1.6, SW16.2, SW17.2, SW18.2, SW19.2, SW20.2
S5: J2.6, Q6.3, RN1.7, SW31.2, SW32.2, SW33.2, SW34.2, SW35.2
S6: J2.7, Q7.3, RN1.8, SW26.2, SW27.2, SW28.2, SW29.2, SW30.2
S7: J2.8, Q8.3, RN1.9, SW36.2, SW37.2, SW38.2, SW39.2, SW40.2
SPK: D2.2, R37.1, R39.1, U7.50
VA0: R6.1, U4.10, U7.21
VA1: R8.1, U4.9, U7.22
VA2: R10.1, U4.8, U7.24
VA3: R12.1, U4.7, U7.29
VA4: R14.1, U4.6, U7.31
VA5: R16.1, U4.5, U7.34
VA6: R18.1, U4.4, U7.33
VA7: R20.1, U4.3, U7.37
VA8: R22.1, U4.25, U7.36
VA9: R23.1, U4.24, U7.30
VA10: R24.1, U4.21, U7.25
VA11: R25.1, U4.23, U7.28
VA12: R26.1, U4.2, U7.41
VA13: R27.1, U4.26, U7.35
VD0: R7.2, U4.11, U7.16
VD1: R9.2, U4.12, U7.15
VD2: R11.2, U4.13, U7.10
VD3: R13.2, U4.15, U7.9
VD4: R15.2, U4.16, U7.11
VD5: R17.2, U4.17, U7.12
VD6: R19.2, U4.18, U7.17
VD7: R21.2, U4.19, U7.18
VRAM_CS: U4.20, U7.20
VRAM_RD: U4.22, U7.27
VRAM_WR: U4.27, U7.39
WAIT: J3.B21, R3.2, U1.24
WR: J3.B19, U1.22, U5.27, U7.6
blue: R51.2, U7.57
bright: R44.2, R45.2, R67.2, U7.51
green: R48.2, U7.54
red: R46.2, U7.55
sync: R63.2, U7.56
~RESET: C1.1, J3.A20, J8.2, U1.26, U7.1
